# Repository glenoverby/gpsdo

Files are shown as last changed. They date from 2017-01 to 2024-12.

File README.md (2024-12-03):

# gpsdo
A GPS Disciplined Oscillator Controller

**There is a newer version of this project in my 'gpsdo3' repository.**

This is a microcontroller based GPS disciplined oscillator.

The purpose of this device is to synchronize a 10MHz voltage controlled
oscillator with the timing signal from a GPS receiver such that the oscillator
operates at exactly 10mhz.

The process is similar to using a phase-locked loop (PLL) but without the
analog components of a PLL.  The details, however, are not so simple.

The PCB design is version 2, which I have not constructed yet.
Version 1 requires many changes to make it work.

The software directory contains several progams:

* Freq-Find  uses a binary search algorithm to search for a target
frequency.  The program searches for 10,000,000 hz, 9,999,999 hz, and
10,000,001 hz.  The PWM values from this program are used to calculate
the PID constants used in the main control program.

* measure, A program that measures the clock frequency at several PWM settings.

* gpsdo-p, Proportional controller which disciplines an oscillator.
I don't use this version anymore.

* gpsdo-pid2, PID (Proportional, Integral, Derivitive) controller which
disciplines an oscillator to a GPS. 
This has code for an Isotemp 134-10 OCXO and a FOX-801 VCO. This version is still a work in progress.

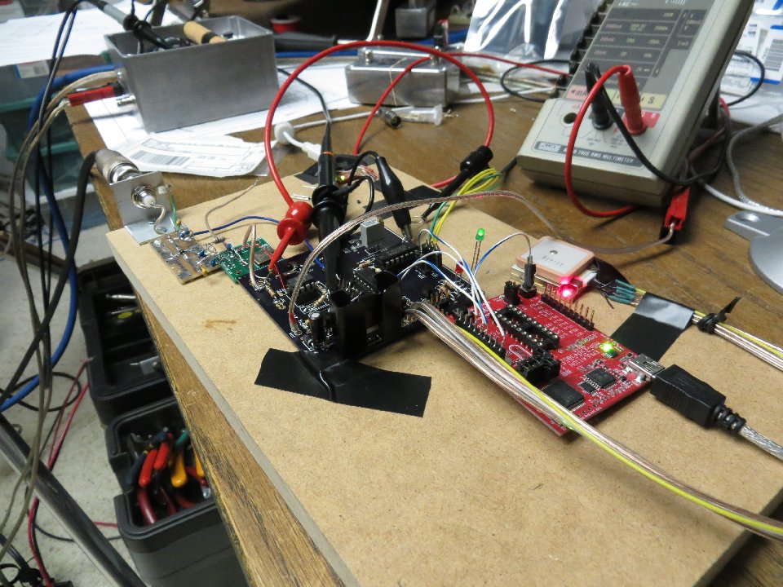
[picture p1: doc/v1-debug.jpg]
Image of board wired up


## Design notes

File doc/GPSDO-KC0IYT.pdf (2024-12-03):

A GPS Disciplined Oscillator Glen Overby, KC0IYT
gpoverby@gmail.com

Introduction
When operating on the microwave bands, I've often needed to have oscillators that are both stable and accurate. These don't always come as one package. Combining the N5AC apolLO synthesized oscillator (also sold by Down East Microwave as the A32), with a good ovenized oscillator, has given me good stability when operating on bands up to 10ghz. I desired an oscillator that is accurate as well as stable. One approach for adding stability is to synchronize an oscillator with the timing signal output from a GPS receiver. This paper presents my experience of using a microcontroller to do the synchronization.

This project started out as a derivative of the article by VE2ZAZ in the October 2006 QEX. The author has a web site describing his project at: http://ve2zaz.net/GPS_Std/GPS_Std.htm. During the adventure of assembling the hardware and writing the software, I've arrived at a somewhat different device.

Theory of Operation
This project replaces a hardware phase-locked loop (PLL), which is frequently used for disciplining oscillators to GPS, with a microcontroller and software.

At the center of this project is a microcontroller which counts clock cycles from the 10MHz oscillator over the time period determined by the GPS one-pulse-per-second(PPS) signal, and the compares that count to the expected count of 10 million. The microcontroller calculates the error and adjusts the oscillator's voltage control input to synchronize it with the GPS signal.

I discovered that the simple approach of adjusting every 1PPS signal had a problem: the GPS signal (or the GPS receiver) has some jitter -- the GPS' 1PPS signal is not accurate to nanoseconds on every clock pulse. I saw this the first first time I put this project into operation: the software would see the oscillator clock count being short one second, and long the next second. I experimented with longer sample times, but still saw similar results. In investigating how other GPS disciplined oscillators work, I discovered that commercial oscillators evaluate the GPS signal over several minutes to several hours. I have followed that approach, and the software on this device now operates on several seconds of data, or a minute of data, depending on what mode it is in.

In addition, I found other conditions which need to be handled:
- When an ovenized oscillator is warming up, its frequency drifts enough that it isn't beneficial to try controlling it. These oscillators typically have an output that can be monitored to show when it has warmed up. During this time, it isn't worth trying to discipline the oscillator to GPS, and trying to do so may leave the controller in a confused state.

- The GPS receiver's 1PPS signal may not be generated when the GPS receiver doesn't have lock (or before the first lock), and is likely to be inaccurate when the GPS receiver does not have a 3D lock. During this time, I don't want to change the oscillator's frequency.

Hardware
Shortly before starting this project, I purchased a TI MSP430 LaunchPad board and was looking for a project to use it for. This microcontroller turned out to be an excellent choice because it's peripherals have features that are ideally suited for this project. The microcontroller on this board, the MSP430G2553, has two counters which can count an external clock at the processor's clock speed. The processor can run from an internal clock at up to 16MHz, thus allowing it to count the 10MHz oscillator directly. The counter includes a sample-and-hold register, which is triggered by an external signal. This feature made the chip ideal for this project. Thus, the 10MHz clock is connected to the counter clock input and the GPS 1PPS signal to the counter's sample and hold trigger.

A second counter in the microcontroller is used to control the oscillator's frequency voltage control. The counter is configured to produce a pulse-width modulated (PWM) output signal, which is filtered to produce a voltage. I use this common technique to generate an analog signal from a microcontroller.

The chip's architects left a complication for me: the counter's sample-and hold has two sample inputs, but both of them use the same chip pins as the serial port! So I had to choose between serial input and serial output. I would like to monitor the GPS' serial stream to see when it has 3D lock, and thus the most accurate time, but the ability to debug and monitor the software using the serial output was more important. Instead, I use a separate microcontroller to monitor the GPS. Lock state comes back to this board as a TTL signal representing lock or no lock.

Circuit Board
My first circuit board required several changes, including the addition of a 'dead bug' chip, as seen in the photograph. The schematic and PCB shown here incorporate all of the lessons I learned while working on the first board. I plan to have boards made from this design in the future.

I designed the board using through-hole components to make assembly at home easier, except in a few places where there was no through-hole component available.

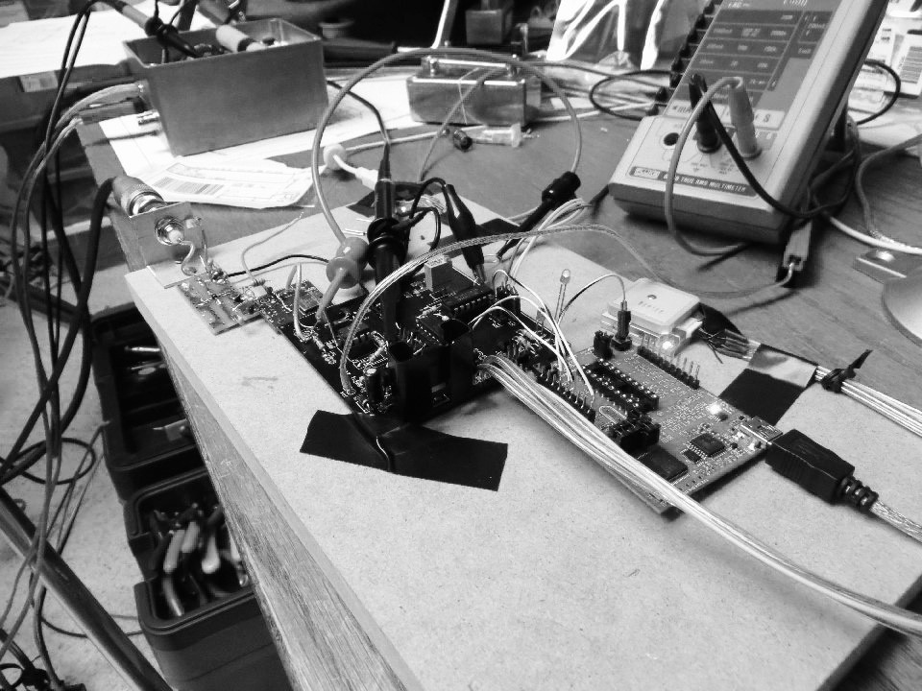
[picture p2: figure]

Board Inputs and Outputs
The circuit board has several headers for input and output:
- Oscillator Input
- Oscillator buffered output
- Oscillator digital output
- GPS
- GPS Serial access
- GPS Lock Detect
- Microcontroller Serial
- Power

The connections in each of these headers is listed in Appendix 1.

Circuit Description
This description references part numbers on the schematic. Overview
The main control flows are:

- The 10MHz oscillator signal coming into the board is amplified, filtered and buffered before connecting to the counter input pin on the microcontroller.
- The GPS' 1PPS signal is buffered and connected to the counter's sample-and-hold trigger input.
- The output from a second counter is is filtered and connected to the oscillator's voltage control input.
- Signal inputs for the Oscillator heater and GPS Lock are buffered and connected to signal input pins.

I learned an interesting buffering technique during this project. 74HCT type logic chips are tolerant of 5V input signals when powered at 3.3V, and when powered at 5V will "see" a 3.3V high signal as a "1" input. The MSP430 microcontroller is a 3.3V device, and some of the inputs (such as the GPS) are 5V, and need conversion down to 3.3V. The LEDs are connected to a 5V power supply and are driven from the microcontroller.

The next sections will cover the inputs to the board and the outputs from it.
Inputs
The 10MHz signal enters the board and is amplified by a MAR-5 (or ERA-1) MMIC, U1. This is to isolate the oscillator from the on board circuitry and to amplify it. The output of the MMIC goes through a 5 pole low-pass filter to eliminate high-frequency harmonics.

I put a second MMIC and filter on the board to drive external devices. I always use a buffer on the output of oscillators, as many of them are load sensitive. That is, their frequency varies depending on the output load, requiring some settling time to come back on frequency after connecting or powering on the devices using their signal.

The 10MHz analog signal goes through a variable resistor, which pulls the signal up to a level that the 74HCT125 buffer will detect it as 1s and 0s.
The GPS' 1 Pulse Per second (1PPS) signal enters the board and goes through a 74HCT125 gate for logic level conversion from 5V to 3.3V.

The oscillator clock and 1PPS signals go to one of the microcontroller's counters, which will be used to measure the clock error.

An ovenized (heated) oscillator often has an output to indicate when the heater has heated up to it's operating temperature. The voltage of this output of an Isotemp oscillator is more than 5V, so it drives a 2N2222 transistor (Q2). If a heater signal is not available, the check will need to be disabled in software.

An input to indicate GPS lock, supplied by another microcontroller, goes through another 74HCT125 gate for voltage conversion from 5V to 3.3V.

Outputs
A Pulse-Width-Modulated output, or PWM, is used to provide an analog output signal. This is driven from a second counter in the microcontroller. A pulse-width modulated signal will, after filtering, have a higher voltage the longer the duty cycle of the signal is, or how long the signal is “on” (or “1”) compared to how long it is “off” (or “0”).

Texas Instruments describes this in Application Report SLAA116. The MSP430x2xx User's Guide describes the counter registers being configured.

This PWM signal is passed through a pair of 1hz low-pass filters which smooth out the pulse to a constant voltage (U3).

The microcontroller serial output port connects to a header and is status and diagnostics. I have several of the SparkFun Electronics DEV-09873 - FTDI Basic Breakout boards for connecting to USB ports.

There are three connectors for GPS interfacing:
- One to the GPS, which provides power, 1PPS signal from the GPS, and TTL level serial
- One to a computer to provide access to the GPS serial port
- One to a board that monitors the GPS serial output and returns it's lock state as a TTL signal

Several LEDs provide status output:
- Red LED is heartbeat of the software, which also serves as a power indicator
- Yellow is the status of the coarse oscillator lock
- Green is the status of the fine oscillator lock
- A Red/Green LED from the GPS lock board indicates if there is GPS 3D lock.

Software
I wrote the software in the "C" language, using TI's MPLAB development environment. I created the project as a CCS project and selected the microcontroller on the LauchPad board.

The software is written as a state machine, and operates one of two Proportional, Integral, Differential (PID) controllers. A PID controller is a control loop feedback mechanism used for process control. It can be mechanical, electrical or software. Those who are not familiar with PID controllers, which I was not at the start of this project, Wikipedia had a good introduction to them.

I found it was useful to have two control domains: a coarse mode that will quickly bring the oscillator close to the desired frequency, using short time samples from the GPS, and a fine mode that refines and maintains the frequency using GPS samples from a longer time period.

States

Check for Status
This is a state that looks for problems:
- The oscillator is cold
- No/Poor GPS lock
- No 1PPS signal from the GPS
- No 10MHz clock from the oscillator

This is the state the controller starts out in, and these values are checked constantly when in one of the PID controller states.
Problem states
These states wait for their respective problems to clear. When the problem clears, the state machine goes to the Coarse Lock state.
Coarse Lock
This is a PID controller using only the Proportional part. This is used to quickly synchronize to GPS 1PPS. A Proportional controller looks at the error (how far off of 10MHz the oscillator is) and changes the PWM's duty cycle based on the error. This is to bring the oscillator close to 10MHz as quickly as possible.

This state counts the oscillator clock for 8 seconds before acting to minimize jitter from the GPS 1PPS signal. The error value is calculated by subtracting the actual clock pulse count from what was expected (8,000,000), and is used to adjust the PWM's duty cycle. It also has an Error Band, where if the count is off by a small amount (currently 1 clock count, or 1/8,000,000) no adjustment is made.

After the error is within +/- 1 count of 10MHz for 5 samples (that is, 5 * 8 seconds) it switches to Fine Lock state.
Fine Lock
The fine lock uses a Proportional, Integral controller. The proportional (P) controller operates once every 60 seconds, while the Integral (I) controller looks at data over several minutes. The goal of fine lock mode is to keep adjustments small, preferably being made by the integral controller.

The proportional controller operates like the coarse lock: the error is used to adjust the PWM's duty cycle. However, the adjustment size used is much smaller to enable fine-tuning of the frequency. In addition, the the error value is saved in a circular list for use by the Integral controller.

The integral controller runs on the minute mark, and uses the sum of the errors from the past 10 minutes to determine if it should apply an additional adjustment to the PWM's duty cycle. Currently, adjustment is done only if there are more than 4 errors in 10 minutes.

If, during any one minute time, a large error (greater than 128 clocks) is detected the state goes back to Coarse Lock.

Configuration
Configuring the software requires choosing parameters for the PID controllers. Many books have been written about tuning PID controllers, and it can be an involved process. This is the technique that I came up with by trial and error.

The PID controller software needs to know how much to change the oscillator's frequency voltage control in order to change the oscillator's frequency by 1hz.

I wrote a program, called freq-find, that that runs on the board and uses it as a frequency counter to search for a PWM “pulse on time” value that sets the oscillator to a desired frequency. I search for three frequencies:
- 9,999,999
- 10,000,000
- 10,000,001

The program uses a binary search for the value in the PWM's counter “on time” register. This is a 16-bit value, and it measures the frequency for one minute per bit. The binary search starts with a counter “pulse on time” register value of 0, then sets the most significant bit to a
1. It measures the oscillator frequency, and if the desired frequency is greater than the measured frequency, it keeps the bit as a 1. Otherwise (if the measured frequency is higher than the desired frequency) it resets it to 0. The search then moves to the next most significant bit and does the same thing. After 16 measurements, the oscillator should be running at the desired frequency.

I get three output values which are register values at three frequencies. I calculate the difference between 9,999,999 and 10,000,000 then between 10,000,000 and 10,000,001 to see how much the pulse on time register must change to move the oscillator by 1hz. Guessing too high can cause the PID controller to oscillate around the desired frequency without ever finding the desired frequency, and these numbers usually aren't the same so I select the lower of the two numbers. Depending on the oscillator, using half of this value may work better, with the downside being a longer coarse lock time.

The program has hard-coded values used by two PID controllers:

- P_FACTOR_FAST (for the coarse lock)
- P_FACTOR_SLOW (for the fine lock)
- I_FACTOR_SLOW (for the fine lock)

The value determined above is set in the P_FACTOR_FAST definition. The fine lock's proportional (P) parameter should be much smaller, about 2% of the coarse parameter, and a fine lock Integral (I) parameter of about half of the fine P parameter seems about right.

Experience and Future Work
The first board I built is used to discipline a FOX 801 10MHz oscillator using a much simpler version of the software than is described here. It accomplishes bringing the oscillator close enough to 10MHz, and keeping it there, to use it to drive a marker (I use a DEMI Weak Signal Source). Having an accurate marker available allows me to tune my 10ghz transverter to the marker and measure where the transverter sees the marker, which I can then use to know where to find other stations. I get stability and accuracy in different packages that work well together and minimize how much gear is mounted together with the dish.

The second board I built disciplines an Isotemp 134-10 10MHz oscillator. During the building of this board, the software was redesigned. The finer control of this oscillator showed that the original algorithm would never find a good lock and a better solution was needed. It was during the building of this board that I began to understand the GPS signal jitter better: it really is accurate only when used over a long period of time. Thus the motivation for switching to 1 minute sample times and 10 minute observing of errors.

The most significant design problem I encountered was caused by driving the LEDs from the same voltage regulator as the microcontroller. I found turning on and off the LEDs would change the oscillator's frequency. I believe this was caused by a dip and rise in the 3.3V power rail used by the microcontroller and thus it's PWM output. The oscillator responded to the voltage change by changing it's frequency! I believe this voltage change was a few hundred micro-volts (and not detectable by my DVM), and I saw it only when driving a synthesized oscillator whose output was being watched on the 10ghz band. I solved this problem by driving the LEDs from the +5V regulator, through a 74HCT125 buffer.

A second version of the PCB has been designed, to fix these problems I found:
- I switched to using the Arduino standard pinout for all serial port headers
- Added more voltage regulators to improve noise isolation
- Stopped powering the 3.3V regulator from the output of the 5V regulator, also for improved noise isolation.
- A second MMIC buffer was added to the board, to integrate one that was built dead-bug style on another board.

I purchased a GPS disciplined oscillator designed by GB7TBL and compared the two by driving a weak signal source with one, and a 10ghz transverter with the other. They “locked” a few hertz away from each other and remained stable after locking.

Not discussed here is a project that provides a GPS lock indicator signal to this board. That project uses an Atmel AVR (similar to an Arduino) to watch the serial data stream from the GPS and provide a TTL signal for lock or no lock. It also provides a GPS lock indicator on an LED.

The software, schematic, and PCB designs are available from: https://github.com/glenoverby/gpsdo

Appendix 1

Serial Ports
The serial ports all use 6-pin headers and the pinout used by Arduino boards. This allows plugging in USB-to-serial adapters made for Arduinos. I have several of the SparkFun Electronics DEV-09873 - FTDI Basic Breakout USB-to-serial adapters.
Oscillator
- 10MHz Input
- VFO Tune Output
- VFO Tune Voltage Input
GPS
This connects to a GPS module.
- GPS Serial input and output
- GPS 1PPS input
- +5V power for the GPS
GPS Serial Access
- Connects to the GPS serial port
GPS Lock Detect
This header is for connecting to a second microcontroller that monitors the GPS serial data for lock.
- GPS Serial Output
- Lock Detect Input
- +5V power
Debug
- Microcontroller Serial Output Misc
- Power (6.5v - 12v)

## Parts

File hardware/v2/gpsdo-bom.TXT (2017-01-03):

Partlist exported from C:/Users/Glen_2/Documents/eagle/GPSDO-2/gpsdo.sch at 8/13/2016 10:31:45 AM

Part    Value       Device             Package              Description                              PROD_ID    VALUE
C1      390pF       CAPPTH             CAP-PTH-SMALL        Capacitor                                                
C2      680pF       CAPPTH             CAP-PTH-SMALL        Capacitor                                                
C3      390pF       CAPPTH             CAP-PTH-SMALL        Capacitor                                                
C4      .1uF        CAPPTH             CAP-PTH-SMALL        Capacitor                                                
C5      .1uF        CAPPTH             CAP-PTH-SMALL        Capacitor                                                
C6      1uF         CAPPTH             CAP-PTH-SMALL        Capacitor                                                
C7      1uF         CAPPTH             CAP-PTH-SMALL        Capacitor                                                
C8      .1uF        CAPPTH             CAP-PTH-SMALL        Capacitor                                                
C9      .1uF        CAPPTH             CAP-PTH-SMALL        Capacitor                                                
C10     4.7uF       10UF-16V-10%(TANT) EIA3216              CAP-00811                                CAP-00811  10uF 
C11     .33uF       CAPPTH             CAP-PTH-SMALL        Capacitor                                                
C12     .1uF        CAPPTH             CAP-PTH-SMALL        Capacitor                                                
C13     .1uF        CAPPTH             CAP-PTH-SMALL        Capacitor                                                
C14     .1uF        CAPPTH             CAP-PTH-SMALL        Capacitor                                                
C15     4.7uF       10UF-16V-10%(TANT) EIA3216              CAP-00811                                CAP-00811  10uF 
C16     .1uF        CAPPTH1            CAP-PTH-5MM          Capacitor                                                
C17     .1uF        CAPPTH             CAP-PTH-SMALL        Capacitor                                                
C18     .001uF      CAPPTH             CAP-PTH-SMALL        Capacitor                                                
C19     .1uF        CAPPTH             CAP-PTH-SMALL        Capacitor                                                
C20     4.7uF       10UF-16V-10%(TANT) EIA3216              CAP-00811                                CAP-00811  10uF 
C21     .1uF        CAPPTH             CAP-PTH-SMALL        Capacitor                                                
C22     10uF        CAP_POLPTH2        CPOL-RADIAL-10UF-25V Capacitor Polarized                                      
C23     .1uF        CAPPTH             CAP-PTH-SMALL        Capacitor                                                
C24     390pF       CAPPTH             CAP-PTH-SMALL        Capacitor                                                
C25     680pF       CAPPTH             CAP-PTH-SMALL        Capacitor                                                
C26     390pF       CAPPTH             CAP-PTH-SMALL        Capacitor                                                
C27     .01uF       CAPPTH             CAP-PTH-SMALL        Capacitor                                                
C28     .33uF       CAPPTH             CAP-PTH-SMALL        Capacitor                                                
C29     .33uF       CAPPTH             CAP-PTH-SMALL        Capacitor                                                
D1      1N4007      DIODEPTH           DIODE-1N4001         Diode                                                    
IC1     74HCT125N   74LS125N           DIL14                Quad bus BUFFER, 3-state                                 
IC2     74HCT125N   74HCT125N          DIL14                Quad bus BUFFER, 3-state                                 
IC3     78L05       V_REG_78XXSINK     TO220-IGO            Voltage Regulator                                        
IC4                 78LXX              78LXX                VOLTAGE REGULATOR                                        
IC5     78L09       78LXX              78LXX                VOLTAGE REGULATOR                                        
JP1                 M06SILK_FEMALE_PTH 1X06                 Header 6                                 CONN-08437      
JP2                 M06SILK_FEMALE_PTH 1X06                 Header 6                                 CONN-08437      
JP3     M02PTH      M02PTH             1X02                 Standard 2-pin 0.1" header. Use with                     
JP4                 M02PTH             1X02                 Header 2                                                 
JP5                 M03PTH             1X03                 Header 3                                                 
JP6                 M03PTH             1X03                 Header 3                                                 
JP7     M02PTH      M02PTH             1X02                 Standard 2-pin 0.1" header. Use with                     
JP8                 M05PTH             1X05                 Header 5                                                 
JP9     M02PTH      M02PTH             1X02                 Standard 2-pin 0.1" header. Use with                     
JP10    M02PTH      M02PTH             1X02                 Standard 2-pin 0.1" header. Use with                     
JP11                M04PTH             1X04                 Header 4                                                 
LED1    YELLOW      LED3MM             LED3MM               LED                                                      
LED2    GREEN       LED3MM             LED3MM               LED                                                      
LED3    RED         LED3MM             LED3MM               LED                                                      
LED4    BLUE        LED3MM             LED3MM               LED                                                      
PROGRAM             M03PTH             1X03                 Header 3                                                 
Q2      2N2222      TRANSISTOR_NPNTO92 TO-92                Transistor NPN                                           
R1      75          R-US_0207/2V       0207/2V              RESISTOR, American symbol                                
R2      5k          R-US_0207/2V       0207/2V              RESISTOR, American symbol                                
R3      5k          R-US_0207/2V       0207/2V              RESISTOR, American symbol                                
R4      100K        R-US_0207/2V       0207/2V              RESISTOR, American symbol                                
R5      100K        R-US_0207/2V       0207/2V              RESISTOR, American symbol                                
R6      0           R-US_0207/2V       0207/2V              RESISTOR, American symbol                                
R7      75          R-US_0207/2V       0207/2V              RESISTOR, American symbol                                
R8      330         R-US_0207/2V       0207/2V              RESISTOR, American symbol                                
R9      330         R-US_0207/2V       0207/2V              RESISTOR, American symbol                                
R10     10K         R-TRIMM3296W       RTRIM3296W           Trimm resistor                                           
R11     47K         R-US_0207/2V       0207/2V              RESISTOR, American symbol                                
R12     1k          R-US_0207/2V       0207/2V              RESISTOR, American symbol                                
R13     6.8k        R-US_0207/2V       0207/2V              RESISTOR, American symbol                                
R14     10k         R-US_0207/2V       0207/2V              RESISTOR, American symbol                                
R15     330         R-US_0207/2V       0207/2V              RESISTOR, American symbol                                
R16     330         R-US_0207/2V       0207/2V              RESISTOR, American symbol                                
R17     5.1K        R-US_0207/2V       0207/2V              RESISTOR, American symbol                                
R18     4.7K        R-US_0207/2V       0207/2V              RESISTOR, American symbol                                
SJ2                 SOLDERJUMPER_2WAYW SJ_2W                Solder Jumper                                            
SV1                 M04PTH             1X04                 Header 4                                                 
U$1     G2XX3---N20 G2XX3---N20        N20                  MSP430G2XX1                                              
U$3     1uH         INDUCTOR1210       1210                 Inductors                                                
U$4     1uH         INDUCTOR1210       1210                 Inductors                                                
U$5     1uH         INDUCTOR1210       1210                 Inductors                                                
U$6     1uH         INDUCTOR1210       1210                 Inductors                                                
U1      LMC6482DIL  LMC6482DIL         DIL08                Dual Op-Amp                                              
U2      MAR-4       MAR-4              VV105                MAR-4 is a MMIC with 8dB of gain to 1GHZ                 
U3      MAR-4       MAR-4              VV105                MAR-4 is a MMIC with 8dB of gain to 1GHZ

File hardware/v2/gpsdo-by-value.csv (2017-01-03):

Qty | Value | Device | Package | Parts | Description | PROD_ID | VALUE
1 |  | 78LXX | 78LXX | IC4 | VOLTAGE REGULATOR
1 |  | M02PTH | 1X02 | JP4 | Header 2
3 |  | M03PTH | 1X03 | JP5, JP6, PROGRAM | Header 3
2 |  | M04PTH | 1X04 | JP11, SV1 | Header 4
1 |  | M05PTH | 1X05 | JP8 | Header 5
2 |  | M06SILK_FEMALE_PTH | 1X06 | JP1, JP2 | Header 6 | CONN-08437
1 |  | SOLDERJUMPER_2WAYW | SJ_2W | SJ2 | Solder Jumper
1 | .001uF | CAPPTH | CAP-PTH-SMALL | C18 | Capacitor
1 | .01uF | CAPPTH | CAP-PTH-SMALL | C27 | Capacitor
11 | .1uF | CAPPTH | CAP-PTH-SMALL | C4, C5, C8, C9, C12, C13, C14, C17, C19, C21, C23 | Capacitor
1 | .1uF | CAPPTH1 | CAP-PTH-5MM | C16 | Capacitor
3 | .33uF | CAPPTH | CAP-PTH-SMALL | C11, C28, C29 | Capacitor
1 | 0 | R-US_0207/2V | 0207/2V | R6 | RESISTOR, American symbol
2 | 100K | R-US_0207/2V | 0207/2V | R4, R5 | RESISTOR, American symbol
1 | 10K | R-TRIMM3296W | RTRIM3296W | R10 | Trimm resistor
1 | 10k | R-US_0207/2V | 0207/2V | R14 | RESISTOR, American symbol
1 | 10uF | CAP_POLPTH2 | CPOL-RADIAL-10UF-25V | C22 | Capacitor Polarized
1 | 1N4007 | DIODEPTH | DIODE-1N4001 | D1 | Diode
1 | 1k | R-US_0207/2V | 0207/2V | R12 | RESISTOR, American symbol
2 | 1uF | CAPPTH | CAP-PTH-SMALL | C6, C7 | Capacitor
4 | 1uH | INDUCTOR1210 | 1210 | U$3, U$4, U$5, U$6 | Inductors
1 | 2N2222 | TRANSISTOR_NPNTO92 | TO-92 | Q2 | Transistor NPN
4 | 330 | R-US_0207/2V | 0207/2V | R8, R9, R15, R16 | RESISTOR, American symbol
4 | 390pF | CAPPTH | CAP-PTH-SMALL | C1, C3, C24, C26 | Capacitor
1 | 4.7K | R-US_0207/2V | 0207/2V | R18 | RESISTOR, American symbol
3 | 4.7uF | 10UF-16V-10%(TANT) | EIA3216 | C10, C15, C20 | CAP-00811 | CAP-00811 | 10uF
1 | 47K | R-US_0207/2V | 0207/2V | R11 | RESISTOR, American symbol
1 | 5.1K | R-US_0207/2V | 0207/2V | R17 | RESISTOR, American symbol
2 | 5k | R-US_0207/2V | 0207/2V | R2, R3 | RESISTOR, American symbol
1 | 6.8k | R-US_0207/2V | 0207/2V | R13 | RESISTOR, American symbol
2 | 680pF | CAPPTH | CAP-PTH-SMALL | C2, C25 | Capacitor
1 | 74HCT125N | 74HCT125N | DIL14 | IC2 | Quad bus BUFFER, 3-state
1 | 74HCT125N | 74LS125N | DIL14 | IC1 | Quad bus BUFFER, 3-state
2 | 75 | R-US_0207/2V | 0207/2V | R1, R7 | RESISTOR, American symbol
1 | 78L05 | V_REG_78XXSINK | TO220-IGO | IC3 | Voltage Regulator
1 | 78L09 | 78LXX | 78LXX | IC5 | VOLTAGE REGULATOR
1 | BLUE | LED3MM | LED3MM | LED4 | LED
1 | G2XX3---N20 | G2XX3---N20 | N20 | U$1 | MSP430G2XX1
1 | GREEN | LED3MM | LED3MM | LED2 | LED
1 | LMC6482DIL | LMC6482DIL | DIL08 | U1 | Dual Op-Amp
4 | M02PTH | M02PTH | 1X02 | JP3, JP7, JP9, JP10 | Standard 2-pin 0.1 header. Use with"
2 | MAR-4 | MAR-4 | VV105 | U2, U3 | MAR-4 is a MMIC with 8dB of gain to 1GHZ
1 | RED | LED3MM | LED3MM | LED3 | LED
1 | YELLOW | LED3MM | LED3MM | LED1 | LED

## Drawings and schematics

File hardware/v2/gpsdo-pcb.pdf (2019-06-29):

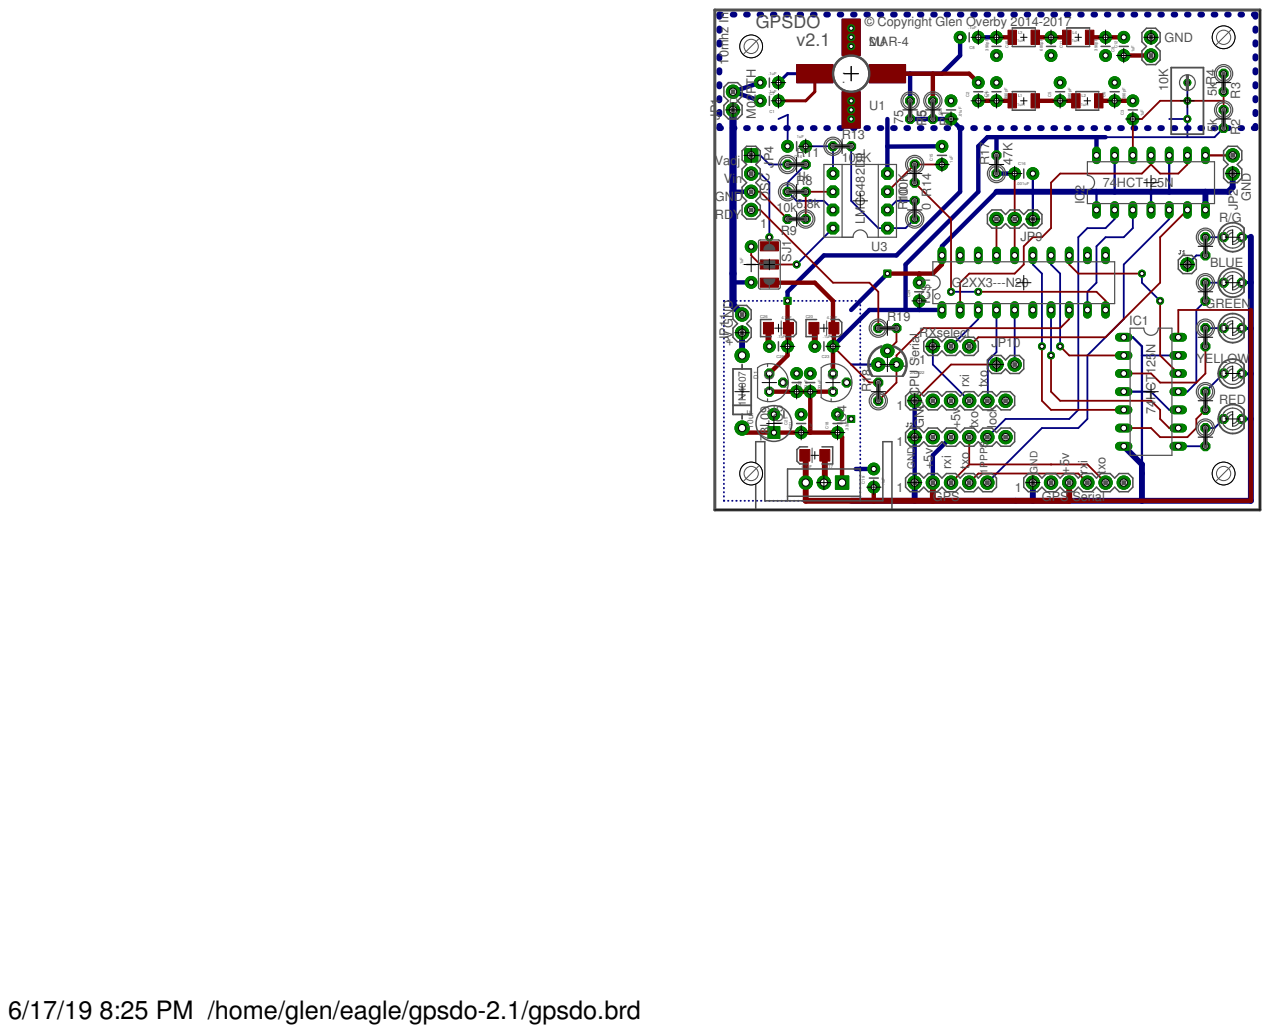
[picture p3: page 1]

GND GND GPS GPS Serial

6/17/19 8:25 PM /home/glen/eagle/gpsdo-2.1/gpsdo.brd

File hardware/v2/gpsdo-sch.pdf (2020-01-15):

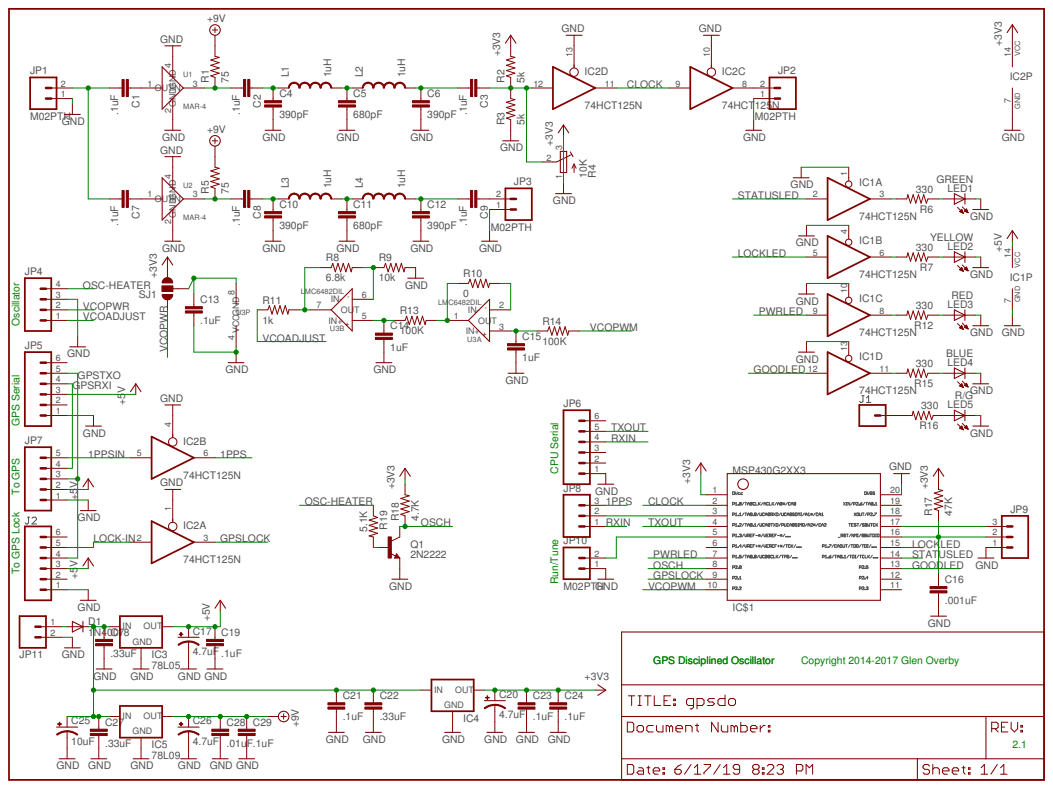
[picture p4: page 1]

To GPS GPS Serial Oscillator

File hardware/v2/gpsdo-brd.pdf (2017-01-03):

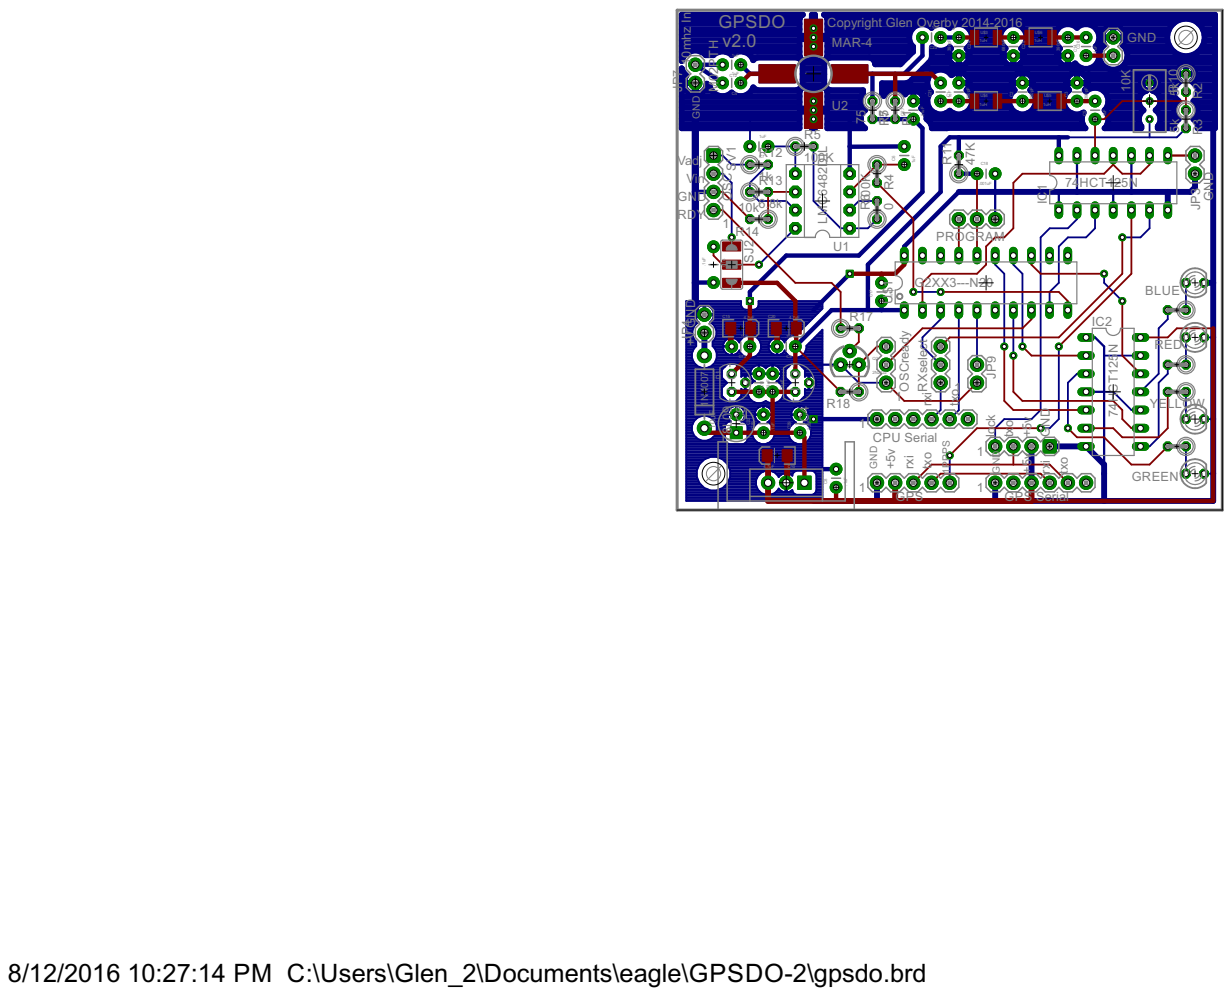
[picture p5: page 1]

GPSDO | .1uF

MAR-4 | 1uH | 1uH | F

8/12/2016 10:27:14 PM C:\Users\Glen_2\Documents\eagle\GPSDO-2\gpsdo.brd

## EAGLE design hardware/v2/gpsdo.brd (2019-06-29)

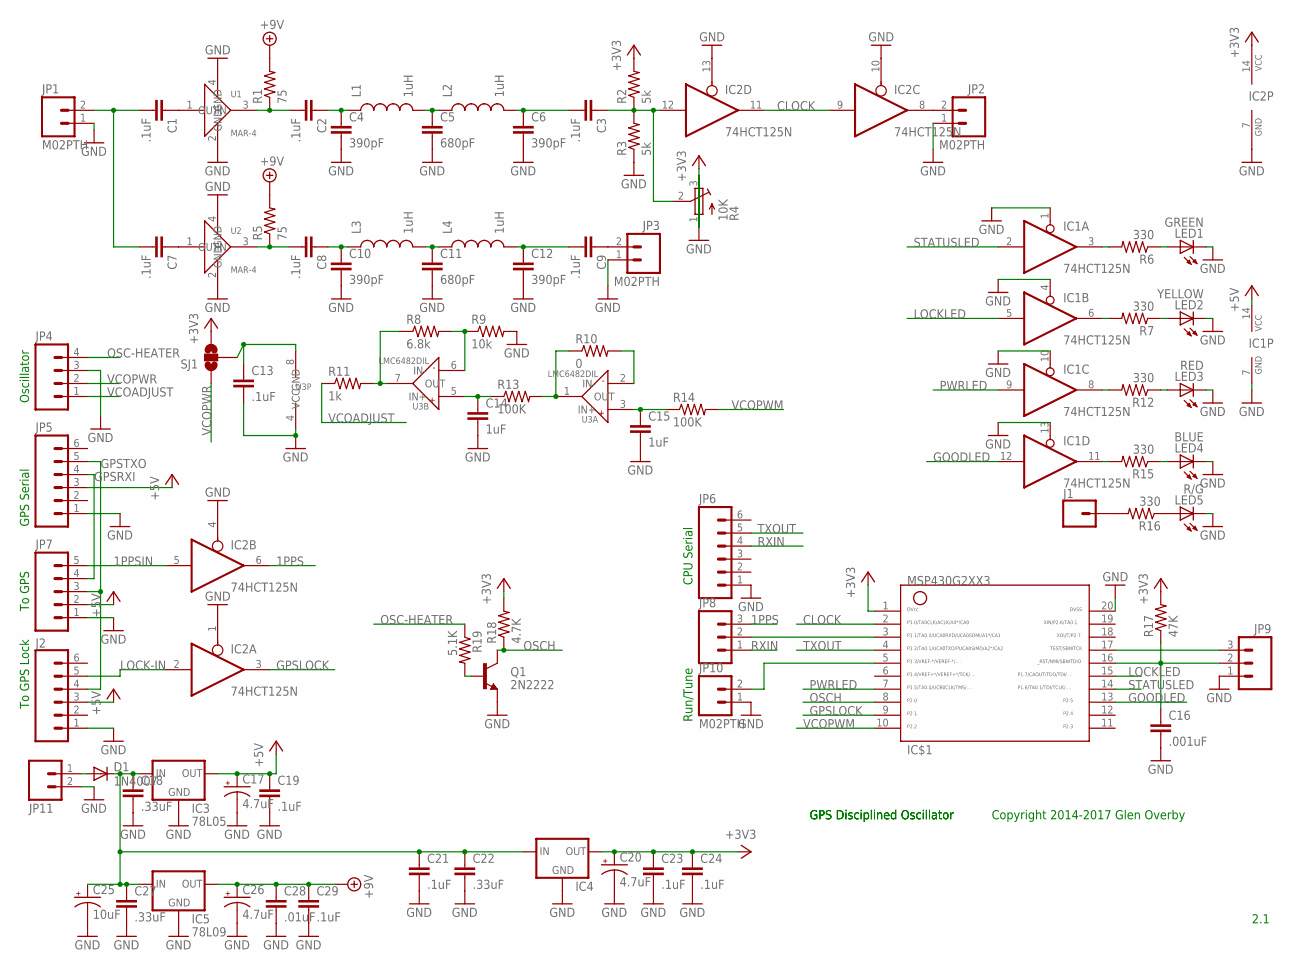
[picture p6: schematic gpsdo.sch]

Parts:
C1, C2, C3, C7, C8, C9, C19, C21, C23, C24, C29: .1uF; CAP-PTH-SMALL
C4, C6, C10, C12: 390pF; CAP-PTH-SMALL
C5, C11: 680pF; CAP-PTH-SMALL
C13: .1uF; CAP-PTH-5MM
C14, C15: 1uF; CAP-PTH-SMALL
C16: .001uF; CAP-PTH-SMALL
C17, C20, C26: 4.7uF; EIA3216
C18, C22, C27: .33uF; CAP-PTH-SMALL
C25: 10uF; CPOL-RADIAL-10UF-25V
C28: .01uF; CAP-PTH-SMALL
D1: 1N4007; DIODE-1N4001
IC1, IC2: 74HCT125N; DIL14
IC3: 78L05; TO220-IGO
IC4: 78LXX
IC5: 78L09; 78LXX
IC$1: G2XX3---N20; N20
J1: CONN_01; 1X01
J2: CONN_06SILK_FEMALE_PTH; 1X06
JP1, JP2, JP3, JP10, JP11: M02PTH; 1X02
JP4: M04PTH; 1X04@1
JP5, JP6: M06SILK_FEMALE_PTH; 1X06@1
JP7: M05PTH; 1X05
JP8, JP9: M03PTH; 1X03
L1, L2, L3, L4: 1uH; 1210
LED1: GREEN; LED3MM
LED2: YELLOW; LED3MM
LED3: RED; LED3MM
LED4: BLUE; LED3MM
LED5: R/G; LED3MM
Q1: 2N2222; TO-92
R1, R5: 75; 0207/2V
R2, R3: 5k; 0207/2V
R4: 10K; RTRIM3296W
R6, R7, R12, R15, R16: 330; 0207/2V
R8: 6.8k; 0207/2V
R9: 10k; 0207/2V
R10: 0; 0207/2V
R11: 1k; 0207/2V
R13, R14: 100K; 0207/2V
R17: 47K; 0207/2V
R18: 4.7K; 0207/2V
R19: 5.1K; 0207/2V
SJ1: SOLDERJUMPER_2WAYW; SJ_2W
U1, U2: MAR-4; VV105
U3: LMC6482DIL; DIL08

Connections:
1PPS: IC2.6 (O), JP8.3
1PPSIN: IC2.5 (I), JP7.5
+3V3: C20.A (+), C23.1, C24.1, IC2.14 (VCC), IC4.OUT, IC$1.1, R2.2, R4.1 (A), R17.2, R18.2, SJ1.3
+5V: C17.A (+), C19.1, IC1.14 (VCC), IC3.OUT, J2.3, JP5.3, JP7.2
+9V: C26.A (+), C28.1, C29.1, IC5.OUT, R1.2, R5.2
CLOCK: IC2.9 (I), IC2.11 (O), IC$1.2
GND: C4.2, C5.2, C6.2, C10.2, C11.2, C12.2, C13.2, C14.2, C15.2, C16.2, C17.C (-), C18.2, C19.2, C20.C (-), C21.2, C22.2, C23.2, C24.2, C25.2 (-), C26.C (-), C27.2, C28.2, C29.2, IC1.1 (OE), IC1.4 (OE), IC1.7 (GND), IC1.10 (OE), IC1.13 (OE), IC2.1 (OE), IC2.4 (OE), IC2.7 (GND), IC2.10 (OE), IC2.13 (OE), IC3.GND, IC4.GND, IC5.GND, IC$1.20, J2.1, JP1.1, JP2.1, JP3.1, JP4.3, JP5.1, JP6.1, JP7.1, JP9.1, JP10.1, JP11.2, LED1.K (C), LED2.K (C), LED3.K (C), LED4.K (C), LED5.K (C), Q1.1 (E), R3.1, R4.3 (E), R9.2, U1.2 (GND), U1.4 (GND), U2.2 (GND), U2.4 (GND), U3.4 (GND)
GOODLED: IC1.12 (I), IC$1.13
GPSLOCK: IC2.3 (O), IC$1.9
GPSRXI: JP5.4, JP7.4
GPSTXO: J2.4, JP5.5, JP7.3
LOCK-IN: IC2.2 (I), J2.5
LOCKLED: IC1.5 (I), IC$1.15
unnamed: LED2.A, R7.1
unnamed: C5.1, L1.2, L2.1
unnamed: C3.2, C6.1, L2.2
unnamed: C1.1, U1.1 (IN)
unnamed: C14.1, R13.1, U3.5 (IN+)
unnamed: R10.1, R13.2, U3.1 (OUT)
unnamed: C15.1, R14.1, U3.3 (IN+)
unnamed: IC$1.3, JP8.2
unnamed: C2.2, R1.1, U1.3 (OUT)
unnamed: C3.1, IC2.12 (I), R2.1, R3.2, R4.2 (S)
unnamed: LED1.A, R6.1
unnamed: R8.1, R11.2, U3.7 (OUT)
unnamed: C1.2, C7.2, JP1.2
unnamed: R10.2, U3.2 (IN-)
unnamed: C11.1, L3.2, L4.1
unnamed: D1.A, JP11.1
unnamed: C9.2, C12.1, L4.2
unnamed: IC$1.5, JP10.2
unnamed: IC1.8 (O), R12.2
unnamed: IC1.11 (O), R15.2
unnamed: C8.2, R5.1, U2.3 (OUT)
unnamed: C16.1, IC$1.16, JP9.2, R17.1
unnamed: C8.1, C10.1, L3.1
unnamed: C7.1, U2.1 (IN)
unnamed: C9.1, JP3.2
unnamed: IC$1.17, JP9.3
unnamed: LED5.A, R16.1
unnamed: J1.1, R16.2
unnamed: IC2.8 (O), JP2.2
unnamed: C13.1, SJ1.2, U3.8 (VCC)
unnamed: C2.1, C4.1, L1.1
unnamed: IC1.3 (O), R6.2
unnamed: IC1.6 (O), R7.2
unnamed: R8.2, R9.1, U3.6 (IN-)
unnamed: LED3.A, R12.1
unnamed: LED4.A, R15.1
unnamed: Q1.2 (B), R19.2
OSC-HEATER: JP4.4, R19.1
OSCH: IC$1.8, Q1.3 (C), R18.1
PWRIN: C18.1, C21.1, C22.1, C25.1 (+), C27.1, D1.C, IC3.IN, IC4.IN, IC5.IN
PWRLED: IC1.9 (I), IC$1.7
RXIN: JP6.4, JP8.1
STATUSLED: IC1.2 (I), IC$1.14
TXOUT: IC$1.4, JP6.5
VCOADJUST: JP4.1, R11.1
VCOPWM: IC$1.10, R14.2
VCOPWR: JP4.2, SJ1.1

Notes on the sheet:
To GPS
GPS Serial
Oscillator
CPU Serial
2.1
Run/Tune
To GPS Lock
GPS Disciplined Oscillator
Copyright 2014-2017 Glen Overby

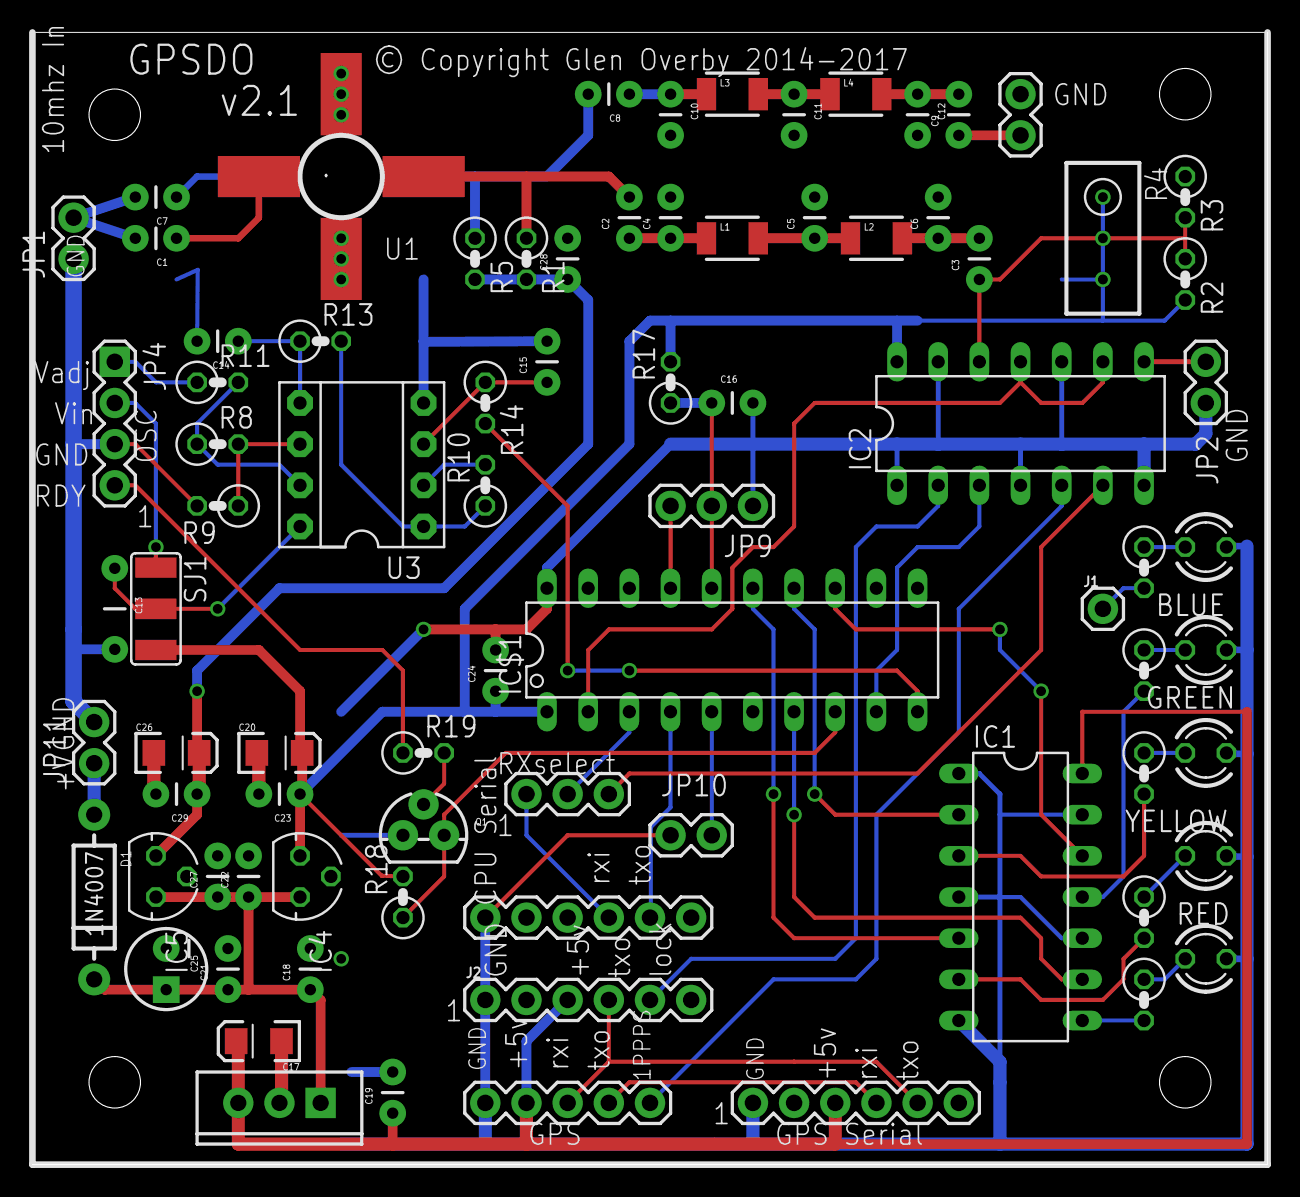
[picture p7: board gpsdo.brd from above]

Board: 2 copper layers, 76.2 x 69.8 mm, 82 parts (1 on the bottom side), 60 nets.

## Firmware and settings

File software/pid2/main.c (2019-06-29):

/*
 * Proportional + Integral Control for a GPS Disciplined Oscillator
 *
 * Copyright 2014-2017 Glen Overby
 * 
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
 */

#include <msp430.h>
#include <stdio.h>
#include <string.h>

/*
 * Hardware Map
 * Timer 0
 *
 * P1.0 TACLK (input)
 * P1.1 1PPS input
 * P1.2 Serial out
 * P1.3 Button (input)
 * P1.4 SMCLK (output)
 * P1.5 LED 3: Red (new)
 * P1.6 LED 2: Green
 * P1.7 LED 1: Yellow (moved)
 *
 * P2.0 input - OSC Good - high when oscillator is cold
 * P2.1 input - GPS Lock
 * P2.2 PWM Output from timer 1
 * P2.5 output LED4: Blue - OSC Good
 *
 * GPSlock: PC0 low when data is good
 *          PC1 high when data is good
 *
 * LED Statuses:
 *  Red     Power
 *  Yellow  Lock Status
 *  Green   Lock Status
 *  Blue    OSC Cold
 *
 *  Blue is on when OSC is cold
 *  Blue blinks if there is no 10mhz clock from the oscillator
 *
 *  Yellow blinks slow if no GPS Lock or No GPS PPS
 *  Yellow blinks when fast algorithm is seeking
 *  Yellow on when fast algorithm has abs(error) < 1
 *
 *  Green blinks for 1 minute when an adjustment has been made
 *  Green on when no adjustment has been made for 1 minute
 */

//#define DEBUG_SECOND
#define DEBUG_SEC_SHORT
//#define DEBUG
#define DEBUG_PID

/* Controller constants */

/*
 * P_FACTOR_FAST was calculated by using a binary search to find frequencies.
 * Slow is 1/20th of that.
 */

/* Isotemp */
#if 1
#define P_FACTOR_FAST   2500 //5000
#define	P_ERRORBAND_FAST 1
#define P_MAX_ERROR		393		// maximum error value (per second) before counter overflow  (32768/P_FACTOR_FAST*SEC)
#define P_FACTOR_SLOW	50
#define P_ERRORBAND_SLOW 1
#define I_FACTOR_SLOW   25
	// tried: 50 - may have set up an oscillation
#define I_ERRORBAND_SLOW 1
#define HAVE_GPSLOCK 0
#define HAVE_OSCCOLD 1
#endif
#if 0
/* Fox 801 */
#define P_FACTOR_FAST   284		// calculated 284
#define	P_ERRORBAND_FAST 1
#define P_MAX_ERROR		920		// maximum error value (per second) before counter overflow  (32768/P_FACTOR_FAST*SEC)
#define P_FACTOR_SLOW	5
#define P_ERRORBAND_SLOW 10
#define I_FACTOR_SLOW   1
#define I_ERRORBAND_SLOW 1
#define HAVE_GPSLOCK 	0
#define HAVE_OSCCOLD 	0
#endif

#define USELED	0
#define SAMPLE_SECONDS  8
#define SAMPLE_MINUTE	60

//#define DEBUG_SECOND  1

#define X12MHZ 0
#define X16MHZ 1

/* Hardware Port definitions */
#define P1Button    0x80
#define P1LED3      0x20        // Red LED
#define P1LED2      0x40        // Green LED
#define P1LED1      0x80        // Yellow LED

#define P2OSC       0x01        // OSC Good input - high when cold
#define P2GPSLOCK   0x02        // GPS Lock - high when no lock
#define P2LED4      0x20        // Blue LED

// State Machine
#define START       0
#define CHECKERRORS 1
#define OSCCOLD     2
#define NOOSCCLOCK  3
#define NOGPSPPS    4
#define NOGPSLOCK   5
#define GOOD        6
// Below states run only on 1PPS clock
#define FASTINIT    7
#define FASTWAIT    8
#define FAST        9
#define SLOWINIT    10
#define SLOW        11


//
//  Data for interrupt handlers
//
volatile long count = 0;                 // counter for 10mhz clock.  Managed by counter overflow interrupt handler
volatile long countadd = 0x10000;        // value to add to count on overflow.
                                // the only time this value is not 65536 is when the 1pps signal arrives.
                                // it is then set to 65536 - captured count.
volatile long capture = 0;               // captured count
volatile char pps = 0;                   // counter from 1pps handler.  Used to detect no 10mhz clock.
char blinkcounter = 0;       // interrupt blink counter
char blink_blue = 0;
char blink_green = 0;
char blink_yellow = 0;
char bcg = 0;
char bcb = 0;
char bcy = 0;

//
// Basic Output: character, string, decimal, hex (4, 16, and 32 bits)
// printf for basic format types.  Calls to printf are expensive, these are shortcuts.
//

// blocking character transmit.
void
tx (char c)
{
    while (!(IFG2 & UCA0TXIFG));        // USCI_A0 TX buffer ready?
    UCA0TXBUF = c;              // TX -> character
}

// printf(%x) of 1 digit.
void
printfx4 (int v)
{
    v &= 0xf;
    v += '0';
    if (v > '9')
        v += 7;
    tx ((char) v);
}

// printf(%x) of 16-bit word.
void
printfx16 (int v)
{
    printfx4 (v >> 12);
    printfx4 (v >> 8 & 0xf);
    printfx4 (v >> 4 & 0xf);
    printfx4 (v & 0xf);
}

// printf(%x) of 32-bit word.
void
printfx32 (long v)
{
    printfx16 (v >> 16);
    printfx16 (v & 0xffff);
}

// printf(%d)
void
printfd (int v)
{
    char output[16];
    void printfs (char *c);
    sprintf (output, "%d", v);
    printfs (output);
}

// printf(%s)
void
printfs (char *c)
{
    for (; *c; c++) {
        if (*c == '\n')
            tx ('\r');
        tx (*c);
    }
}

// newline (CR & LF)
void
nl ()
{
    tx ('\r');
    tx ('\n');
}

// 
// Set blink state
//
void
ledstate(int blue, int green, int yellow)
{
    switch(blue) {
    case 0:     P2OUT &= ~0x20;         // Blue LED off
        break;
    case 10:
    case -1:    P2OUT |= 0x20;          // Blue LED on
        break;
    }
    blink_blue = blue;

#if USELED
    switch(green) {
    case 0:
    	P1OUT &= ~0x40;         // Green LED off
    	bcg = 0;
        break;
    case -1:
    	P1OUT |= 0x40;          // Green LED on
    	bcg = 0;
        break;
    default:
    	bcg = green;
    }
    blink_green = green;

    switch(yellow) {
    case 0:
    	P1OUT &= ~0x80;         // Yellow LED off
    	bcy = 0;
        break;
    case -1:
    	P1OUT |= 0x80;          // Yellow LED on
    	bcy = 0;
        break;
    default:
    	bcy = yellow;
    }
    blink_yellow = yellow;
#endif /* USELED */
}

//
// Configure the microcontroller ports.
//
int
config(void)
{
    WDTCTL = WDTPW | WDTHOLD;   // Stop watchdog timer

    // Set processor clock speed
    // From TI's example program: msp430g2xx3_dco_calib
    //12Mhz
    if (CALBC1_12MHZ == 0xFF)   // If calibration constant erased
    {
        return (1);             // do not load, trap CPU!!
    }
    DCOCTL = 0;                 // Select lowest DCOx and MODx settings
#if X12MHZ
    BCSCTL1 = CALBC1_12MHZ;     // Set range
    DCOCTL = CALDCO_12MHZ;      // Set DCO step + modulation*/
#endif
#if X16MHZ
    BCSCTL1 = CALBC1_16MHZ;     // Set range
    DCOCTL = CALDCO_16MHZ;      // Set DCO step + modulation*/
#endif

    // Configure Timer TA0 to count clock pulses on P1.0 with a capture input on P1.1.
    // From TI's example program: msp430g2xx3_ta_03.c (with modifications)
    TA0CTL = MC_2 + TAIE;       // TACLK, continuous mode, interrupt
    P1SEL |= 0x01;              // Function: TA0.TACLK

    // Enable Capture/Compare register 0
    TA0CCTL0 = CM1 | SCS | CAP | CCIE;  // Capture on CCIxA on falling edge, synchronous
    TA0CCTL1 = 0;
    TA0CCTL2 = 0;

    P1DIR &= ~0x02;             // input
    P1SEL |= 0x02;              // Function: CCI0A

    //P1DIR &= ~0x08;                                                   // P1.3 (Button) as an input
    //P1REN |= 0x08;                                                    // P1.3 pull-up resistor enable

    // PWM using timer 1 on P2.2-10
    // This goes through a low-pass filter and connects to the oscillator's voltage
    // control input.
    // From TI's example program: msp430g2xx3_ta_16.c (with modifications)
    P2DIR |= 0x04;              // P2.2 output
    P2SEL |= 0x04;              // P2.2 TA1 options
    TA1CCR0 = 65535;            // PWM Period


    TA1CCTL1 = OUTMOD_7;        // CCR1 reset/set
    TA1CCR1 = 1;
    TA1CTL = TASSEL_2 + MC_1;   // SMCLK, up mode - counts to TA1CCR0

    P1DIR |= 0xf0;              // P1.6 is LED2, P1.7 is LED1 (new), P1.5 is POWER
    P1OUT &= ~0xf0;
    P2DIR &= ~0x01;             // P2.0 input - OSC Good
    P2DIR &= ~0x02;             // P2.1 input - GPS Lock
    P2DIR |= 0x20;              // P2.5 output - OSC Good (Blue)
    P2OUT &= ~0x20;             // turn Blue LED off

    // Serial port from TI's example program: msp430g2xx3_uscia0_uart_01_9600 (modified)
    P1SEL |= BIT2;              // P1.2=TXD
    P1SEL2 |= BIT2;             // P1.2=TXD
    UCA0CTL1 |= UCSSEL_2;       // Uart clock from SMCLK
#if X12MHZ
    UCA0BR0 = 0xe0;             // 12MHz 9600
    UCA0BR1 = 4;                // 12MHz 9600
#endif
#if X16MHZ
    UCA0BR0 = 0x80;             // 16MHz 9600
    UCA0BR1 = 6;                // 16MHz 9600
#endif
    UCA0MCTL = UCBRS0;          // Modulation UCBRSx = 1
    UCA0CTL1 &= ~UCSWRST;       // **Initialize USCI state machine**
    //IE2 |= UCA0RXIE;                          // Enable USCI_A0 RX interrupt

    UCA0TXBUF = '!';
    nl ();

    P1OUT |= 0x20;              // turn on power/status LED

    //_BIS_SR(LPM0_bits + GIE);                 // Enter LPM0 w/ interrupt
    _BIS_SR (GIE);              // Enable interrupt
    return 0;
}

int
main (void)
{
    unsigned int pwm_duty_cycle = 1;    // PWM duty cycle ~ voltage
    long sum = 0;               // sum of captured counts during (counter) pulses
    long wlc = 0;               // loop counter - experimental counter.  0x40961 iterations per second
    int counter = -10;          // count of 1pps pulses before acting.
    char lockcount = 0;         // iterations that had lock.

    //  initialized to a value not used by the state check
    char state = 0;             // state machine
    char oldstate = 0;          //   previous state, for reporting changes

    long error;                 // calculated error from 10mhz
    int adjust;                 // adjustment of PWM duty cycle
    int P, I;			// PID adjustment values
    int Ihist;                  // I history

    char slowlock = 0;		// number of minutes with no adjustment

    config();

    printfs("PID2-reorg-0703"); nl();

    TA1CCR1 = pwm_duty_cycle;
    ledstate(0,0,0);

    capture = 0;
    counter = -1;
    while (1) {
        wlc++;
        // Report when state has changed
        if (state != oldstate) {
            printfs("> state: ");
            printfd(oldstate);
            printfs(" -> ");
            printfd(state);
            nl();

            oldstate = state;
        }

        //
        // States that are run repeatedly
        //
        switch (state) {

        case START:
                /* FALL THROUGH */
        case CHECKERRORS:   // a start-up state that checks for errors before
                            // continuing
                state = GOOD;   // If no error checks fail, enter GOOD state
                /* FALL THROUGH */
        default:
            // Check for errors

            // Check if Oscillator is cold
#if HAVE_OSCCOLD
            if (P2IN & P2OSC) {
                ledstate(-1, 0, 0);     // Blue LED on
                state = OSCCOLD;
                break;
            }
#endif
            // Check for GPS Lock Lost
#if HAVE_GPSLOCK
            if (P2IN & P2GPSLOCK) {
                ledstate(0, 0, 5);      // slow blink yellow
                state = NOGPSLOCK;
                break;
            }
#endif
            // Check for missing 1PPS signal
            if (count > 150000000) {     // If no PPS clocks for 15 seconds
                ledstate(0, 0, 3);      // Slow blink yellow
                state = NOGPSPPS;
            }

#if 0
// >> Test this
            // Check for missing 1PPS signal
            // loop count measured at 264545/second.
            if (wlc > 2645450) {        // If no PPS clocks for 10 seconds
                ledstate(0, 0, 3);      // Slow blink yellow
                state = NOGPSPPS;
                printfs("loop count PPS check failed\n");
            }
#endif

            // Check for missing oscillator signal
            if (pps > 14) {
                // 15 seconds of clocks from GPS but no 10mhz clock pulses
                // toggle the red LED to indicate the device is functioning
                ledstate(1, 0, 0);      // blink blue
                state = NOOSCCLOCK;
                pps = 0;
            }
            break;

        case OSCCOLD:   // Oscillator is cold
            // check if oscillator is still cold
            if ((P2IN & P2OSC) == 0) {
                ledstate(0, 0, 0);      // blue (all) off
                state = CHECKERRORS;
            }
            break;

        case NOOSCCLOCK:
            // check if there has been any clocks from the oscillator.  
            // The 'pps' counter is tracked for this purpose: it is set by
            // the 1pps interrupt, and is reset when there is a non-zero
            // capture count.
            if (pps) {
                ledstate(0, 0, 0);
                state = CHECKERRORS;
            }
            break;

        case NOGPSPPS:
            // check if there has been any GPS 1PPS signals
            //if (capture > 10 || pps) {   // yes, I've had a capture
             // above line toggled states back and forth between CHECKERRORS and NOGPSPPS
            if (pps) {   // I've had a capture
                ledstate(0, 0, 0);
                state = CHECKERRORS;
            }
            break;

        case NOGPSLOCK:
            if ((P2IN & P2GPSLOCK) == 0) {
                ledstate(0, 0, 0);
                state = CHECKERRORS;
            }
            break;

        case GOOD:
            // State between one of the error states and one of the
            // operational states.  State is set to GOOD by CHECKERRORS
            // as the "no errors" state.
            // Hand off to 1PPS based actions
            state = FASTINIT;
            break;
        }

        // Look for a 1PPS signal
        if (capture != 0) { // && state > GOOD
            pps = 0;                        // reset pps counter.
                                            // used as oscillator loss check

            if (counter >= 0) {
                // sum clock counts only when positive.
                // negative count allows for stabilization after changing
                // the oscillator
                sum += capture;
            }

            // 1 second report: Letter Count Error
#ifdef DEBUG_SECOND
            error = 10000000 - capture;     // Error relative to a 10mhz clock rate
            tx ('A' + counter);
            tx (' ');
            printfx32 (capture);
            tx (' ');
            printfd (error);
            tx (' ');
            //printfx32 (wlc);     // while(1) loop counter.  see about using it
                                // as a fault detection counter.
            printfx32(sum);
            nl ();
#endif /* DEBUG_SECOND */
#ifdef DEBUG_SEC_SHORT
            error = 10000000 - capture;     // Error relative to a 10mhz clock rate
            printfd (error);
            tx (' ');
#endif

            capture = 0;
            wlc = 0;

            //
            // States that occur on a 1PPS clock
            //
            switch (state) {

            // I could put the GOOD state here

            case FASTINIT:      // initialize for fast wait
                counter = 5;
                state = FASTWAIT;
                ledstate(0, 0, 1);  // set LED to yellow blink
                lockcount = 0;
                break;

            case FASTWAIT:      // wait for counters to stabilize
                // switching from one of the error states to here is not 
                // synchronized with 1PPS, so the count in capture may not be
                // good. Wait for the partial second, and for good measure 
                // wait one more second.
                if (--counter <= 0) {
                    // yellow LED continues to blink
                    state = FAST;
                    sum = 0;
                }
                break;

            case FAST:
                // FAST Synchronize to GPS 1PPS. This uses a Proportional controller and
                // a factor that is estimated to be a full step.
                // Count for several seconds before acting to minimize GPS jitter.
                adjust = 0;
                counter++;
                if (counter >= SAMPLE_SECONDS) {
#ifdef DEBUG_SEC_SHORT
                    nl();
#endif
                    counter = 0;

                    error = (SAMPLE_SECONDS * 10000000) - sum;

                    //
                    // Determine LED status
                    //
                    // If error > 10 (1 in 10,000,000) : blink Yellow LED
                    // If error < 10 && > 2 (1 in ?) : slow blink Yellow LED
                    // If error <= 1 : solid on Yellow LED
                    //
                    if (abs (error) < 2) {
                        ledstate(0, 0, -1); // turn on Yellow LED
                    } else {
                        ledstate(0, 0, 1);  // blink Yellow LED
                    }

                    // an "error band" of +- 1
                    if (abs (error) <= P_ERRORBAND_FAST) {
                        lockcount++;
                        if (lockcount > 5) {
                            // After no ajustments are needed for 5 seconds, switch to the
                            // slow control program.
                            state = SLOWINIT;
                        }
                    } else {
                        lockcount = 0;
                        if (error > P_MAX_ERROR)
                        	error = P_MAX_ERROR;
                        if (error < 0-P_MAX_ERROR)
                        	error = 0-P_MAX_ERROR;
                        // Make an adjustment.
                        // The proportional factor is tuned for 1 second samples
                        // so divide by seconds
                        adjust = (P_FACTOR_FAST / SAMPLE_SECONDS) * error;
                    }

                    // Try to prevent underflow or overflow of the PWM duty cycle.
                    // First, by limiting the adjustment value
                    if (adjust > 32000) {
                        adjust = 32001;
                    } else if (adjust < -32000) {
                        adjust = -32000;
                    }

                    // second, by trying to detect overflow / underflow
                    if (adjust > 0
                        && pwm_duty_cycle + adjust < pwm_duty_cycle) {
                        // Overflow
                        pwm_duty_cycle = 0x8001;
                    } else if (adjust < 0
                               && pwm_duty_cycle + adjust > pwm_duty_cycle) {
                        pwm_duty_cycle = 0x8000;
                    } else {
                        // No overflow or underflow.  Make the adjustment.
                        pwm_duty_cycle += adjust;
                    }

                    // status message
                    printfs("== ");
                    printfx16(pwm_duty_cycle);
                    tx(' ');
                    printfd(error);
                    tx(' ');
                    printfd(adjust);
                    nl();

                    if (adjust) {
                        TA1CCR1 = pwm_duty_cycle;
                        // If an adjustment was made, skip the current second's count
                        counter = -1;
                    }
                    sum = 0;
                }
                break;

            case SLOWINIT:
                // initialize for slow control program.
                slowlock = 0;
                sum = 0;
                Ihist = 0;
                ledstate(0, 1, 0);
                state = SLOW;
                counter = -2;

                /* FALL THROUGH */
            case SLOW:
                // Slow tracking of GPS.  Measures offset from GPS over a minute
                // and makes small adjustments.
                // The P factor is typically 5% of the full step between frequencies.
                counter++;
            	if (counter >= SAMPLE_MINUTE) {
#ifdef DEBUG_SEC_SHORT
                    nl();
#endif
                    error = (60 * 10000000) - sum;
#ifdef DEBUG
                    printfs("S ");
                    printfx32 (sum);
                    tx(' ');
                    printfd(error);
                    nl();
#endif /* DEBUG */

                    counter = 0;
                    sum = 0;

                    if (abs(error) > 128) {  // glitch or something. 
                        // may need to lower this to catch drift problems that
                        // should cause switching back to FAST
                        state = FASTINIT;
                        printfs("** ERROR ");
                        printfx32 (error);
                        nl();
                    } else {
                    	adjust = 0;
                    	P = I = 0;
                        // Proportional control, based on the 1 minute error.
                    	if (abs(error) > P_ERRORBAND_SLOW) {
                    		P = error * P_FACTOR_SLOW;
                    	}

                        // Integral control
                        // Look at the last several minutes of error data
                        // for a trend + or -. When there is a trend of
                        // errors in one direction, make an adjustment.

                        // Integral history & calculation:
                        // When the error is positive or negative, and the I history
                        // matches (pos/neg), then increase the count in the direction
                        // of the error.
                        // If it flips from +1 to -1 (or -1 to +1), this require an extra
                        // cycle before counting.
                        if (error < 0 && Ihist <= 0) {
                            Ihist--;
                        } else if (error > 0 && Ihist >= 0) {
                            Ihist++;
                        } else {
                            Ihist = 0;
                        }

                        if (abs(Ihist) > I_ERRORBAND_SLOW) {
                            I = I_FACTOR_SLOW * Ihist;
                        }
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

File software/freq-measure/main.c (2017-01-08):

/*
 * freq-measure: measure the clock frequency at various PWM settings.
 *
 * This can be used to find the maximum and minimum tuning values, and to check
 * PID factors.
 *
 * Copyright 2014-2017 Glen Overby
 * 
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
 * P1.0	TACLK (input)
 * P1.1 1PPS input
 * P1.2 Serial out
 * P1.3 Button (input)
 * P1.4 SMCLK (output)
 * P1.5
 * P1.6 LED 2
 * P1.7 LED 1 (moved)
 *
 * P2.2 PWM Output from timer 1
 */
#include <msp430.h> 
#include <stdio.h>

#define X12MHZ 1
#define X16MHZ 0

#define REPORT_C
#define AVERAGE_SIZE	8			// samples in average.  power of 2 for efficiency.
#define FRACTIONBITS	0

long count = 0;
long countadd = 0x10000;
long capture = 0;
int capflags = 0;
int cappins = 0;
int counth = 0, countl = 0;
int captureh = 0, capturel = 0, capturec = 0;

void tx(char c)
{
	  while (!(IFG2&UCA0TXIFG));                // USCI_A0 TX buffer ready?
	  UCA0TXBUF = c;                            // TX -> character
}

printfx4(int v)
{
	v &= 0xf;
	v += '0';
	if (v > '9')
		v += 7;
	tx((char)v);
}
void printfx16(int v)
{
	printfx4(v >> 12);
	printfx4(v >> 8 & 0xf);
	printfx4(v >> 4 & 0xf);
	printfx4(v & 0xf);
}

// printf(%x) of 32-bit word.
void printfx32(long v)
{
	printfx16(v>>16);
	printfx16(v&0xffff);
}

void printfld(long v)
{
	char output[16];
	char *c;
	sprintf(output, "%ld", v);
	for(c=output; *c; c++) {
		tx(*c);
	}
}

// printf(%d)
void printfd(int v)
{
	char output[16];
	char *c;
	sprintf(output, "%d", v);
	for(c=output; *c; c++) {
		tx(*c);
	}
}

void nl()
{
	tx('\r');
	tx('\n');
}

int main(void)
{
	unsigned int	pwm_duty_cycle = 65535;					// PWM duty cycle ~ voltage
	long sum=0, sum10s=0, sum30s=0;
	int counter=-1;
	unsigned int ti;		// table index
	static const unsigned int freqtable[] = {
#ifdef SMALLSTEPS
			32768,		32000,		31900,
			31800,		31700,		31600,		31500,
			31400,		31300,		31200,		31100,
			31090,		31080,		31070,		31060,
			31050,		31040,		31030,		31020,
			31010,		31005,		31000,
#endif
//			65534,		60000,		50000,		40000,
//			30000,		20000,		10000,		1,
#if 0
			1,			5041,		10082,		15123,
			20164,		25205,		30246,		35287,
			40328,		45369,		50410,		55451,
			60492,		65533,
#endif
//			0x7700,
//			31768,		32768,		33768,
//			16384,		32768,		49152,
			1,		16384,		32768,		49152,	65534,
			0
	};
	WDTCTL = WDTPW | WDTHOLD;	// Stop watchdog timer

    // Set processor clock speed
    // From TI's example program: msp430g2xx3_dco_calib
    //12Mhz
     if (CALBC1_12MHZ==0xFF)					// If calibration constant erased
     {
       return(1);                              // do not load, trap CPU!!
     }
     DCOCTL = 0;                               // Select lowest DCOx and MODx settings
#if X12MHZ
     BCSCTL1 = CALBC1_12MHZ;                   // Set range
     DCOCTL = CALDCO_12MHZ;                    // Set DCO step + modulation*/
#endif
#if X16MHZ
     BCSCTL1 = CALBC1_16MHZ;                   // Set range
     DCOCTL = CALDCO_16MHZ;                    // Set DCO step + modulation*/
#endif

     // Configure Timer TA0 to count clock pulses on P1.0 with a capture input on P1.1.
     // From TI's example program: msp430g2xx3_ta_03.c (with modifications)
     //TA0CTL = TASSEL_2 + MC_2 + TAIE;           // SMCLK, continuous mode, interrupt
     // Count on P1.0
     //TA0CTL = TASSEL_0 + MC_2 + TAIE;           // ?CLK, continuous mode, interrupt
     TA0CTL = MC_2 + TAIE;           			// TACLK, continuous mode, interrupt
     P1SEL |= 0x01;								// Function: TA0.TACLK

     // Enable Capture/Compare register 0
     //TA0CCTL0 = CM1 + CCIS0 + SCS + CAP;		// Capture on CCIxA
     //TA0CCTL0 = CM1 + SCS + CAP + CCIE;			// Capture on CCIxA on falling edge, synchronous
     TA0CCTL0 =  CM1 | SCS | CAP | CCIE;		// Capture on CCIxA on falling edge, synchronous
     TA0CCTL1 = 0;
     TA0CCTL2 = 0;

     P1DIR &= ~0x02;							// input
     P1SEL |= 0x02;								// Function: CCI0A

     P1DIR &= ~0x08;							// P1.3 (Button) as an input
     P1REN |= 0x08;								// P1.3 pull-up resistor enable

     // Enable Capture/Compare register 1
//     TA0CCTL1 = CM0 + SCS + CAP + CCIE;		// Capture on CCIxA
//    P1DIR &= ~0x04;							// input
//    P1SEL |= 0x04;								// Function: CCI1A

     // Enable Capture/Compare register 2.
     // table 12 indicates that TA0.2 connects to PinOsc
//     TA0CCTL2 = CM1 + CCIS0 + SCS + CAP + CCIE;		// Capture on CCIxA
//     P2SEL |= 0x40;

     // PWM using timer 1 on P2.2-10
     // This goes through a low-pass filter and connects to the oscillator's voltage
     // control input.
     // From TI's example program: msp430g2xx3_ta_16.c (with modifications)
     P2DIR |= 0x04;                            // P2.2 output
     P2SEL |= 0x04;                            // P2.2 TA1 options
     TA1CCR0 = 65535;                          // PWM Period
     TA1CCTL1 = OUTMOD_7;                  		// CCR1 reset/set
     //TA1CCR1 = 8192;                           // CCR1 PWM duty cycle
     TA1CCR1 = pwm_duty_cycle;
     TA1CTL = TASSEL_2 + MC_1;                 // SMCLK, up mode - counts to TA1CCR0
     //TA1CTL = TASSEL_2 + MC_2;                 // SMCLK, continuous up

     // These two configuration lines will use a signal on XIN for the PWM clock
     //TA1CTL = TASSEL_1 | MC_2 ;                 // ACLK, continuous up
     //BCSCTL3 = LFXT1S0 | LFXT1S1;				// sets LFXT1 to external clock on XIN

     P1DIR |= 0x10;								// P1.4 output
     P1SEL |= 0x10;								// P1.4 is SMCLK

     P1DIR |= 0xc0;								// P1.6 is LED2, P1.7 is LED1 (new)
     P1OUT &= ~0xc0;

     // Serial port from TI's example program: msp430g2xx3_uscia0_uart_01_9600 (modified)
     //P1SEL = BIT1 + BIT2 ;                     // P1.1 = RXD, P1.2=TXD
     //P1SEL2 = BIT1 + BIT2 ;                    // P1.1 = RXD, P1.2=TXD
     P1SEL |= BIT2 ;                           // P1.2=TXD
     P1SEL2 |= BIT2 ;                          // P1.2=TXD
     UCA0CTL1 |= UCSSEL_2;                     // Uart clock from SMCLK
     // 104 0 for 1mhz
#if X12MHZ
     UCA0BR0 = 0xe0;                           // 12MHz 9600
     UCA0BR1 = 4;                              // 12MHz 9600
#endif
#if X16MHZ
     UCA0BR0 = 0x80;                           // 16MHz 9600
     UCA0BR1 = 6;                              // 16MHz 9600
#endif
     UCA0MCTL = UCBRS0;                        // Modulation UCBRSx = 1
     UCA0CTL1 &= ~UCSWRST;                     // **Initialize USCI state machine**
     //IE2 |= UCA0RXIE;                          // Enable USCI_A0 RX interrupt

     UCA0TXBUF = '!';
     //printfx16(CALBC1_12MHZ);
     //tx(' ');
     //printfx16(CALDCO_12MHZ);
     nl();

     //_BIS_SR(LPM0_bits + GIE);                 // Enter LPM0 w/ interrupt
     _BIS_SR(GIE);                 				// Enable interrupt
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

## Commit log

2017-01-03 Import of documentation and board design.
    [gpsdo-bom.csv, gpsdo-by-value.csv, gpsdo-by-value.ods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]
2017-01-04 update schematic.
2019-06-18 Device description - CSVHFS Paper review version
2019-06-29 Rename components
    [gpsdo.brd, gpsdo.sch]
2020-01-15 Current schematic PDF

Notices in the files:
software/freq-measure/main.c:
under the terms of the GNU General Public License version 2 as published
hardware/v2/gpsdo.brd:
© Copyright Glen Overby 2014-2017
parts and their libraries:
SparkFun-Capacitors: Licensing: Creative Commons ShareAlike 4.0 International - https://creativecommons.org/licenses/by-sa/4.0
